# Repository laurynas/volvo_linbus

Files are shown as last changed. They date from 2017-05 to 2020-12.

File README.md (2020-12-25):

# VOLVO LIN BUS READER

Simple Arduino + MCP2004 based reader. Reads steering wheel keys via LIN bus.

Part of [retrofitting of Android Auto to Volvo RTI project](https://github.com/laurynas/volvo_crankshaft).

Tested with **Volvo V50 2006**.

## Scheme

Arduino UNO + MCP2004 LIN transceiver.

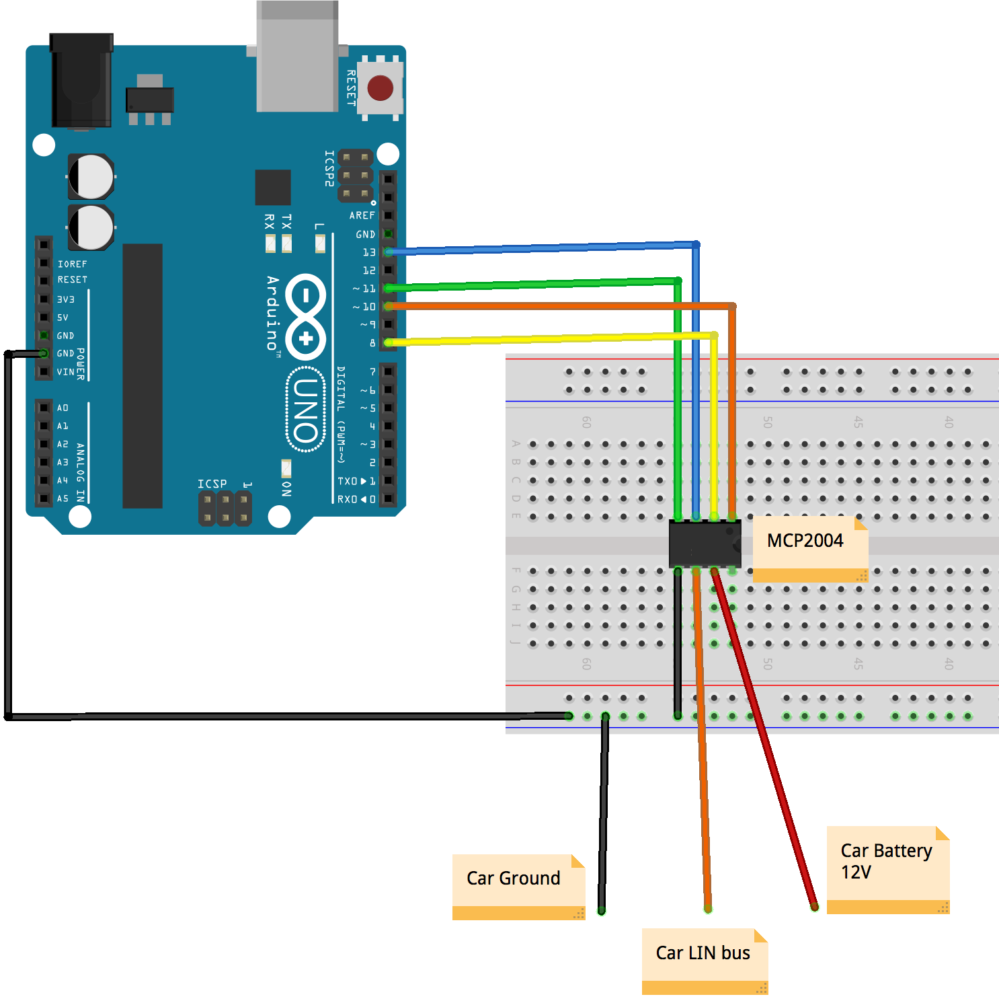
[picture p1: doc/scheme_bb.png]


## Connector

Connection to LIN bus can be found behind Volvo Infotainment Control Module (ICM).

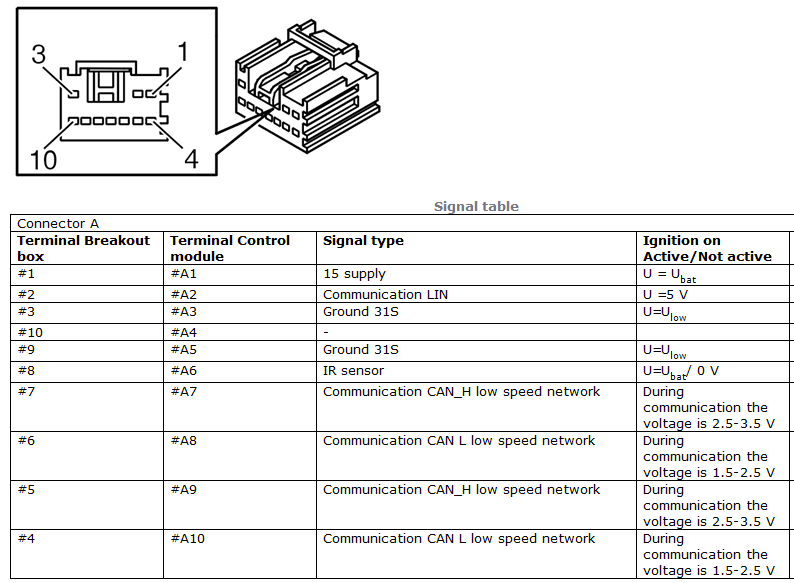
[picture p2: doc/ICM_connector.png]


Video instructions how to remove stereo from Volvo V50 floating dash:<br>
[https://www.youtube.com/watch?v=Xo5NpBt04qs](https://www.youtube.com/watch?v=Xo5NpBt04qs)

## LIN Message

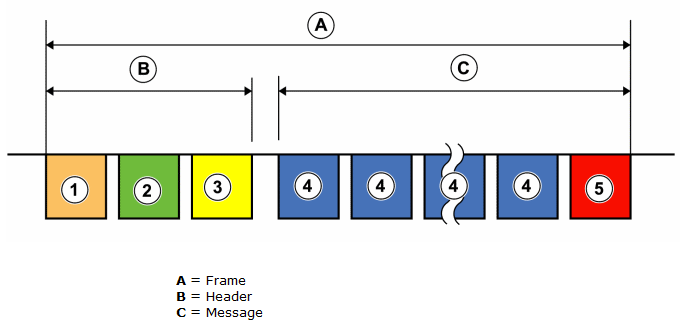
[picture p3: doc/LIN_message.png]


A message on LIN is called a frame and consist of the following parts:

1. **Synchronisation interrupt.** Used to wake slave nodes that are in sleep mode. 
Synchronisation field. The synchronisation field helps slave nodes to synchronise with their master node's clock frequency, in order for messages sent to be received correctly. 
2. **Identification field.** Contains information about the contents of the message. All nodes can read and respond to a message, yet only one node has the right to send a response to the message. Which node has the right to answer the message (send response data) is evident from the identifier. 
3. **Data information.** The data sent can be two to eight bytes long. The data information is sent with the least significant bit first. 
4. **Checksum.** The checksum is a way for slave notes to check whether the received message has been transferred correctly, or if any disturbance can have occurred during the transmission which has corrupted the data. If an error has occurred in a message during transmission from the master node to the slave node, i.e. the checksum calculated by the slave node does not correspond, the slave node will erase the message and await the next message sent from the master node. 

## References

* [MCP2004 documentation](http://www.microchip.com/wwwproducts/en/MCP2004)

## Credits

Frame checksum calculation based on [Arduino LINBUS Gadgets code](https://github.com/zapta/linbus/).

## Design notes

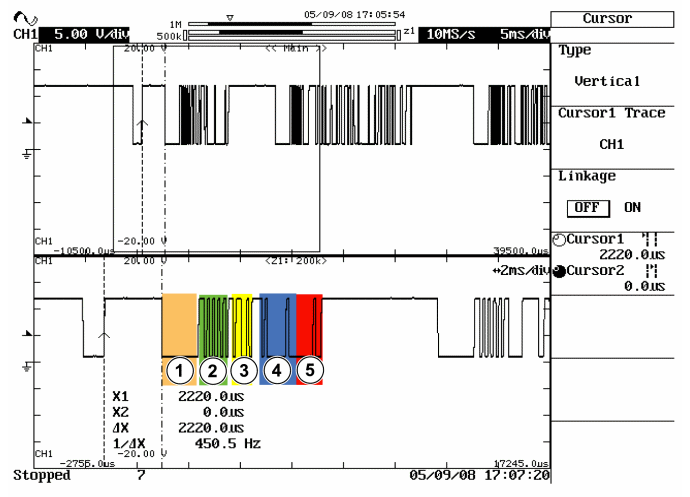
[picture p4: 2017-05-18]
doc/LIN_oscilloscope.png

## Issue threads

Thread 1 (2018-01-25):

Break read

sinurb, 2018-01-25:
Hi,

I see in your code, you don't read the 13 bits "break" in LIN frame, how does it work then?

Thanks

wchpikus, 2018-03-31:
Hi
Could you comfir, that master always send frame to key with id=0x20 and then keys answer?
And other question,where is the master lin? On the icm?

laurynas, 2020-11-23:
Missed the question, sorry. I just used [LINBUS frame analyzer code](https://github.com/zapta/linbus/tree/master/analyzer/arduino). I break frames using SYN field:
https://github.com/laurynas/volvo_linbus/blob/master/volvo_linbus.ino#L66

Closed 2020-11-23.

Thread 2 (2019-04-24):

lin bus isue

wchpikus, 2019-04-24:
Hello.
Did you know that icm is master of lin?
I trying different chip but no success

iDoka, 2019-05-24:
My assumption:
steering wheel buttons are master on LIN-bus

wchpikus, 2019-05-24:
ok, i test and know..icm as master..
buttons are slave.

laurynas, 2020-11-23:
Yes, looks like [ICM is the master](https://f01.justanswer.com/rmldaytona/456ac45a-4c24-442e-8600-86b9e86ad75d_alt.pdf)

Closed 2020-11-23.

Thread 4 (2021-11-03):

Connect it with Android Radio

kuemme01, 2021-11-03:
Hello there,

this is an interesting project I think! Nice Results.
I have equipped my V50 with an Android Radio connected via AUX cable to be able to use Apple CarPlay in my 2012 Volvo. Problem is I can't use the Steeringwheel controls on the back because they are not connected.

Do you think I can make it work via your solution? So connect the Lin cable to MCP2004 to maybe ESP8266 and then via USB to the Android Radio. What do I need for the Radio to recognize the inputs? Can I make the ESP8266 with your code will be recognized as keyboard or how does this work?

Hope you can give me some advices.

Greetings
Erik

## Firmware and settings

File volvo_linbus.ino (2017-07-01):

#include <SoftwareSerial.h>

// https://github.com/zapta/linbus/tree/master/analyzer/arduino
#include "lin_frame.h"

// Pins we use for MCP2004
#define RX_PIN 10
#define TX_PIN 11
#define FAULT_PIN 14
#define CS_PIN 8

#define SYN_FIELD 0x55
#define SWM_ID 0x20

SoftwareSerial LINBusSerial(RX_PIN, TX_PIN);

//Lbus = LIN BUS from Car
//Vss = Ground
//Vbb = +12V

// MCP2004 LIN bus frame:
// ZERO_BYTE SYN_BYTE ID_BYTE DATA_BYTES.. CHECKSUM_BYTE

// Volvo V50 2007 SWM key codes

// BTN_NEXT       20 0 10 0 0 EF
// BTN_PREV       20 0 2 0 0 FD
// BTN_VOL_UP     20 0 0 1 0 FE
// BTN_VOL_DOWN   20 0 80 0 0 7F
// BTN_BACK       20 0 1 0 0 F7
// BTN_ENTER      20 0 8 0 0 FE
// BTN_UP         20 1 0 0 0 FE
// BTN_DOWN       20 2 0 0 0 FD
// BTN_LEFT       20 4 0 0 0 FB
// BTN_RIGHT      20 8 0 0 0 F7

// IGN_KEY_ON     50 E 0 F1


byte b, i, n;
LinFrame frame;

void setup() {
  pinMode(LED_BUILTIN, OUTPUT);

  // Open serial communications to host (PC) and wait for port to open:
  Serial.begin(9600, SERIAL_8E1);
  Serial.println("LIN Debugging begins");

  LINBusSerial.begin(9600);

  pinMode(CS_PIN, OUTPUT);
  digitalWrite(CS_PIN, HIGH);

  pinMode(FAULT_PIN, OUTPUT);
  digitalWrite(FAULT_PIN, HIGH);

  frame = LinFrame();
}

void loop() {
  if (LINBusSerial.available()) {
    b = LINBusSerial.read();
    n = frame.num_bytes();

    if (b == SYN_FIELD && n > 2 && frame.get_byte(n - 1) == 0) {
      digitalWrite(LED_BUILTIN, HIGH);
      frame.pop_byte();
      handle_frame();
      frame.reset();
      digitalWrite(LED_BUILTIN, LOW);
    } else if (n == LinFrame::kMaxBytes) {
      frame.reset();
    } else {
      frame.append_byte(b);
    }
  }
}

void handle_frame() {
  if (frame.get_byte(0) != SWM_ID)
    return;

  // skip zero values 20 0 0 0 0 FF
  if (frame.get_byte(5) == 0xFF)
    return;

  if (!frame.isValid())
    return;


  dump_frame();
}

void dump_frame() {
  for (i = 0; i < frame.num_bytes(); i++) {
    Serial.print(frame.get_byte(i), HEX);
    Serial.print(" ");
  }
  Serial.println();
}

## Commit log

2017-05-18 Add code and instructions
    [scheme.fzz]
2017-05-18 Add more details about MCP2004
    [scheme.fzz]
2017-07-01 Adjust enter / back button codes
